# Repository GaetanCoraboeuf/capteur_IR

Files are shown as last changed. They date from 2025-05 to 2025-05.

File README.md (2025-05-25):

# capteur_IR

Le but de ce projet est de concevoir un capteur de détection de mouvement par infrarouges. Cette solution est modulable et scalable en plus de son coût de fabrication faible.

## Table des Matières

- [Description](#description)
- [Hardware](#hardware)
- [Software](#software)
- [Évolutions](#évolutions)
- [Contributeurs](#contributeurs)

## Description

Il est composé de deux grande parties:
 - Electronique (ESP32 + capteur IR LHI968)
 - Software (code C++ + dashboard avec base de données)

Ce projet a été fait par des étudiants.

## Hardware

La carte électronique est conçu pour être un sheld pour une Esp32 devkit V1.
On a utilisé KiCad pour la concevoir et générer le modèle 3D.
Et on l'a réalisé en prototypage rapide sur CNC.

Voici le schéma électronique :
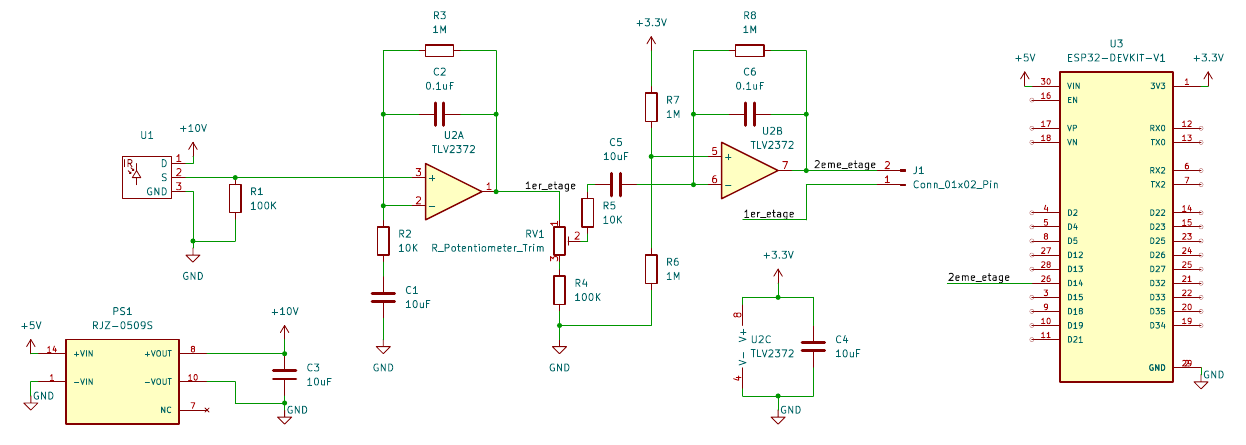
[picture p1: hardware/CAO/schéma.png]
Schéma élec


Et voici la réalisation final :
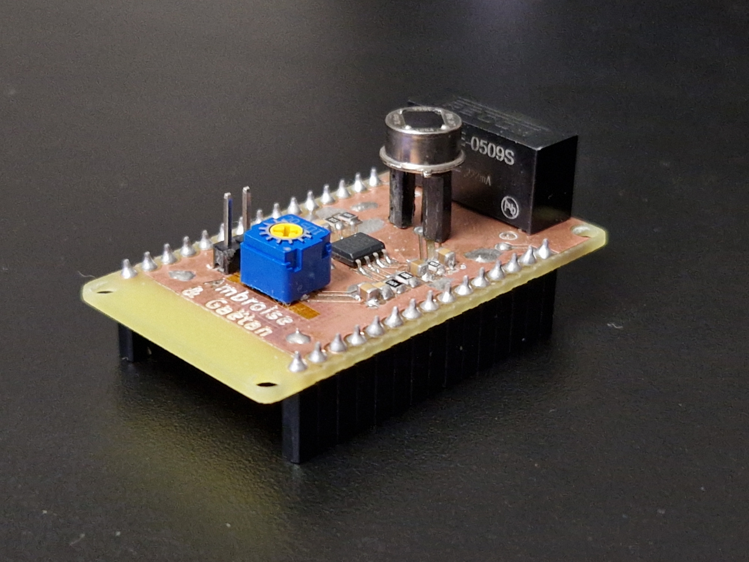
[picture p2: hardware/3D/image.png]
rendu carte finie


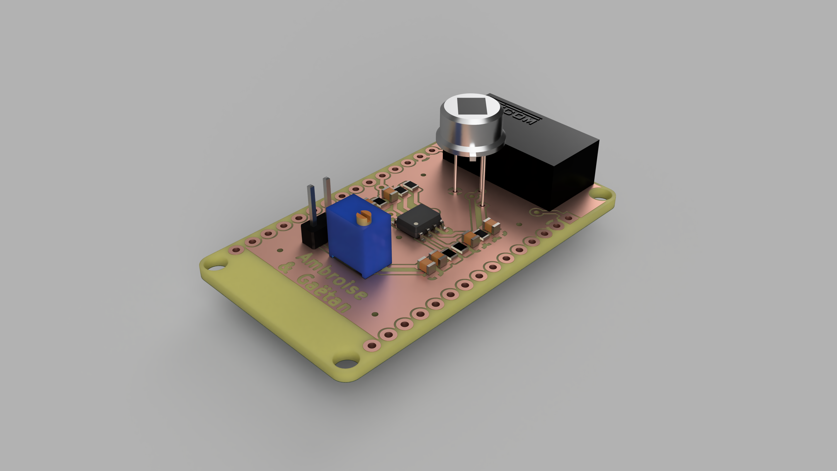
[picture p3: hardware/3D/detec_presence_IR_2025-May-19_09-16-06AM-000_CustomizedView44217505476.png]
rendu 3d de la carte


## Software

Ce code permet de se connecter à une base de données influxDB via une requête POST.
De notre côté on a choisi d'héberger cette base de données sur une Raspberry Pi et de l'exploiter avec Grafana.

Ce code envoie simplement la tesion du capteur toutes les 100ms à la base de données et tente une reconection au Wi-Fi chaque fois qui pert le signal.

## Boitier

Nous avons aussi conçu un boitier pour le capteur. Il est imprimé en 3D et permet d'intégrer tous les composants de manière esthétique et fonctionnelle. (merci à BHP pour la conception du boitier)

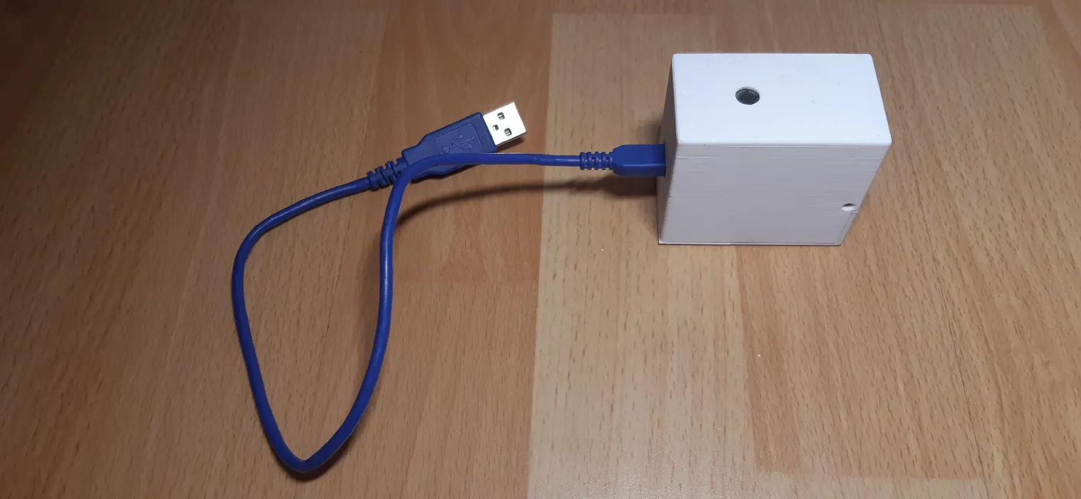
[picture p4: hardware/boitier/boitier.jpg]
boitier

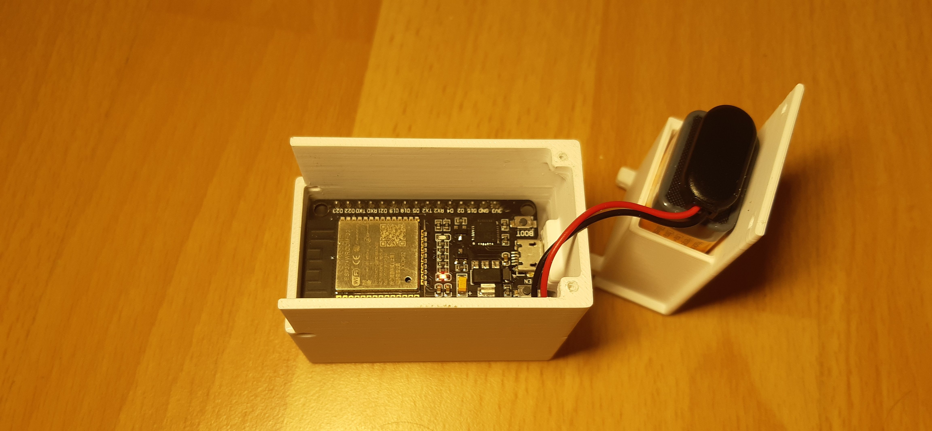
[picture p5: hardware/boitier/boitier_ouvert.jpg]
boitier ouvert


## Évolutions

- [x] Remplacement du convertisseur boost par une pile 9V (ce convertisseur n'est pas recomandé)
- [ ] Lecture de la tension de batterie avec un pont diviseur
- [ ] Scan des periphériques Bluethooth à proximité (distinction autorisé/non-autorisé)
- [ ] Detection sonore, bruit ambiant
- [ ] Camera avec intégration IA (OpenCV)
- [ ] Utiliser l'horloge temps réel de l'ESP32 pour horodater les valeurs grace à un serveur de temps (plus précis)
- [ ] Mettre en place un buffer en cas de coupure de connection pour ne pas perdre de valeurs

## Contributeurs

Ambroise Nedey-Crettaz <br />
Gaëtan Corabœuf

Sur la proposition de : <br />
M.Dumas

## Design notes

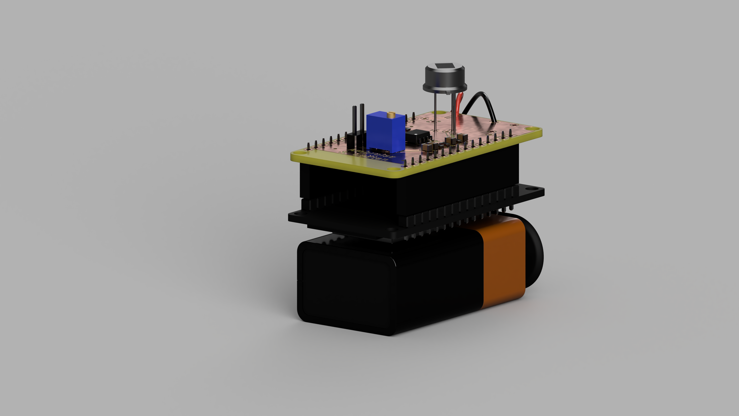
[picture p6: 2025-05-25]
hardware/3D/d7317d31-32a5-4699-8c03-88a2d2deff08.PNG

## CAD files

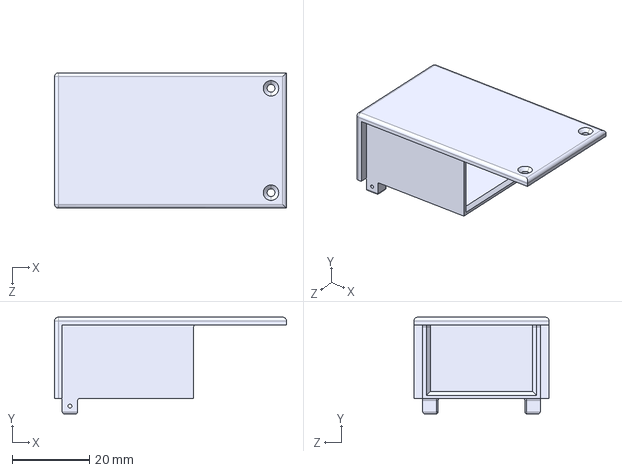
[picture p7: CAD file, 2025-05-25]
hardware/boitier/couvercle.STEP
60.0 x 25.0 x 35.0 mm

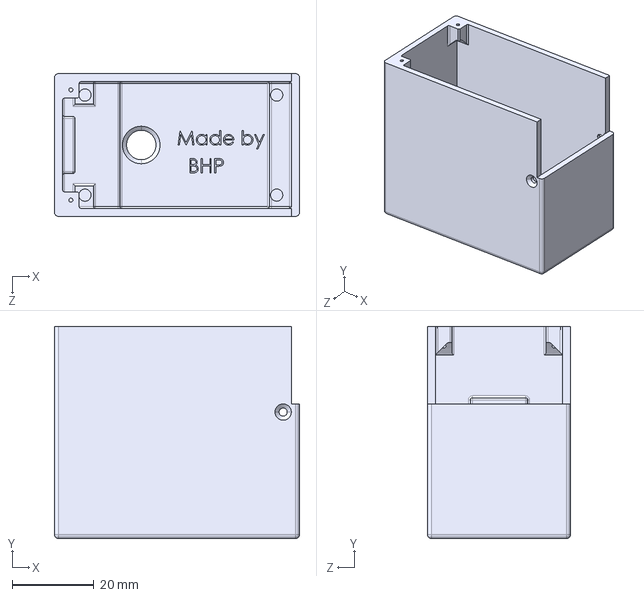
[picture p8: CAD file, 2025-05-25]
hardware/boitier/boite.STEP
60.0 x 52.0 x 35.0 mm

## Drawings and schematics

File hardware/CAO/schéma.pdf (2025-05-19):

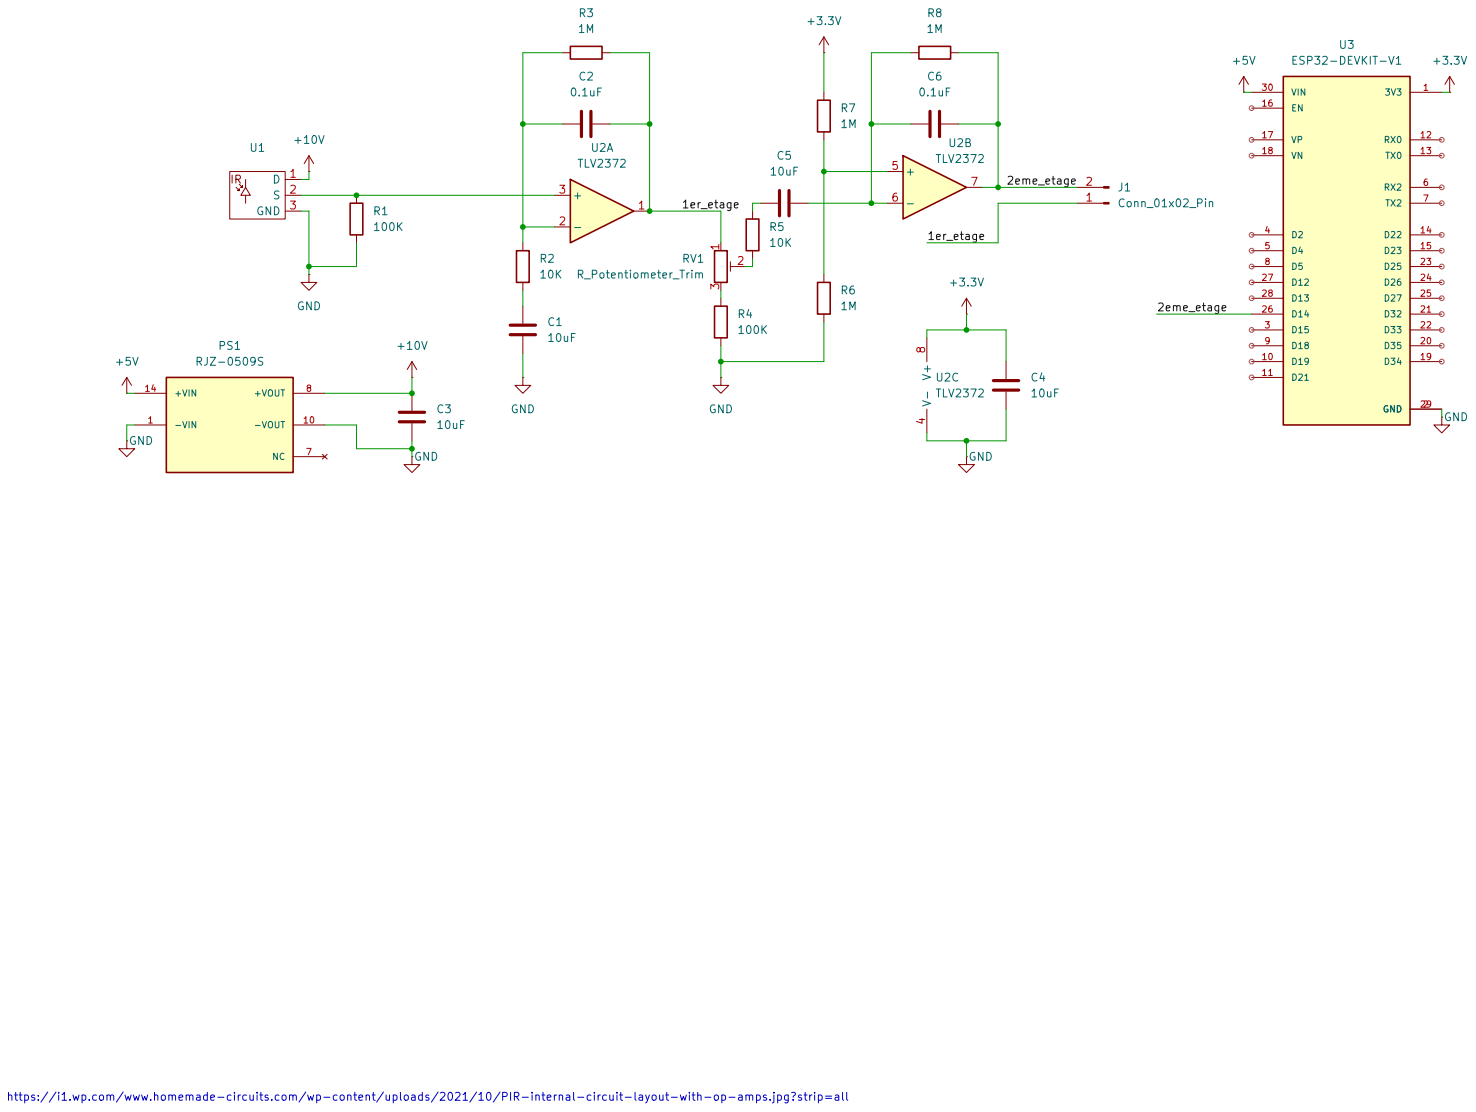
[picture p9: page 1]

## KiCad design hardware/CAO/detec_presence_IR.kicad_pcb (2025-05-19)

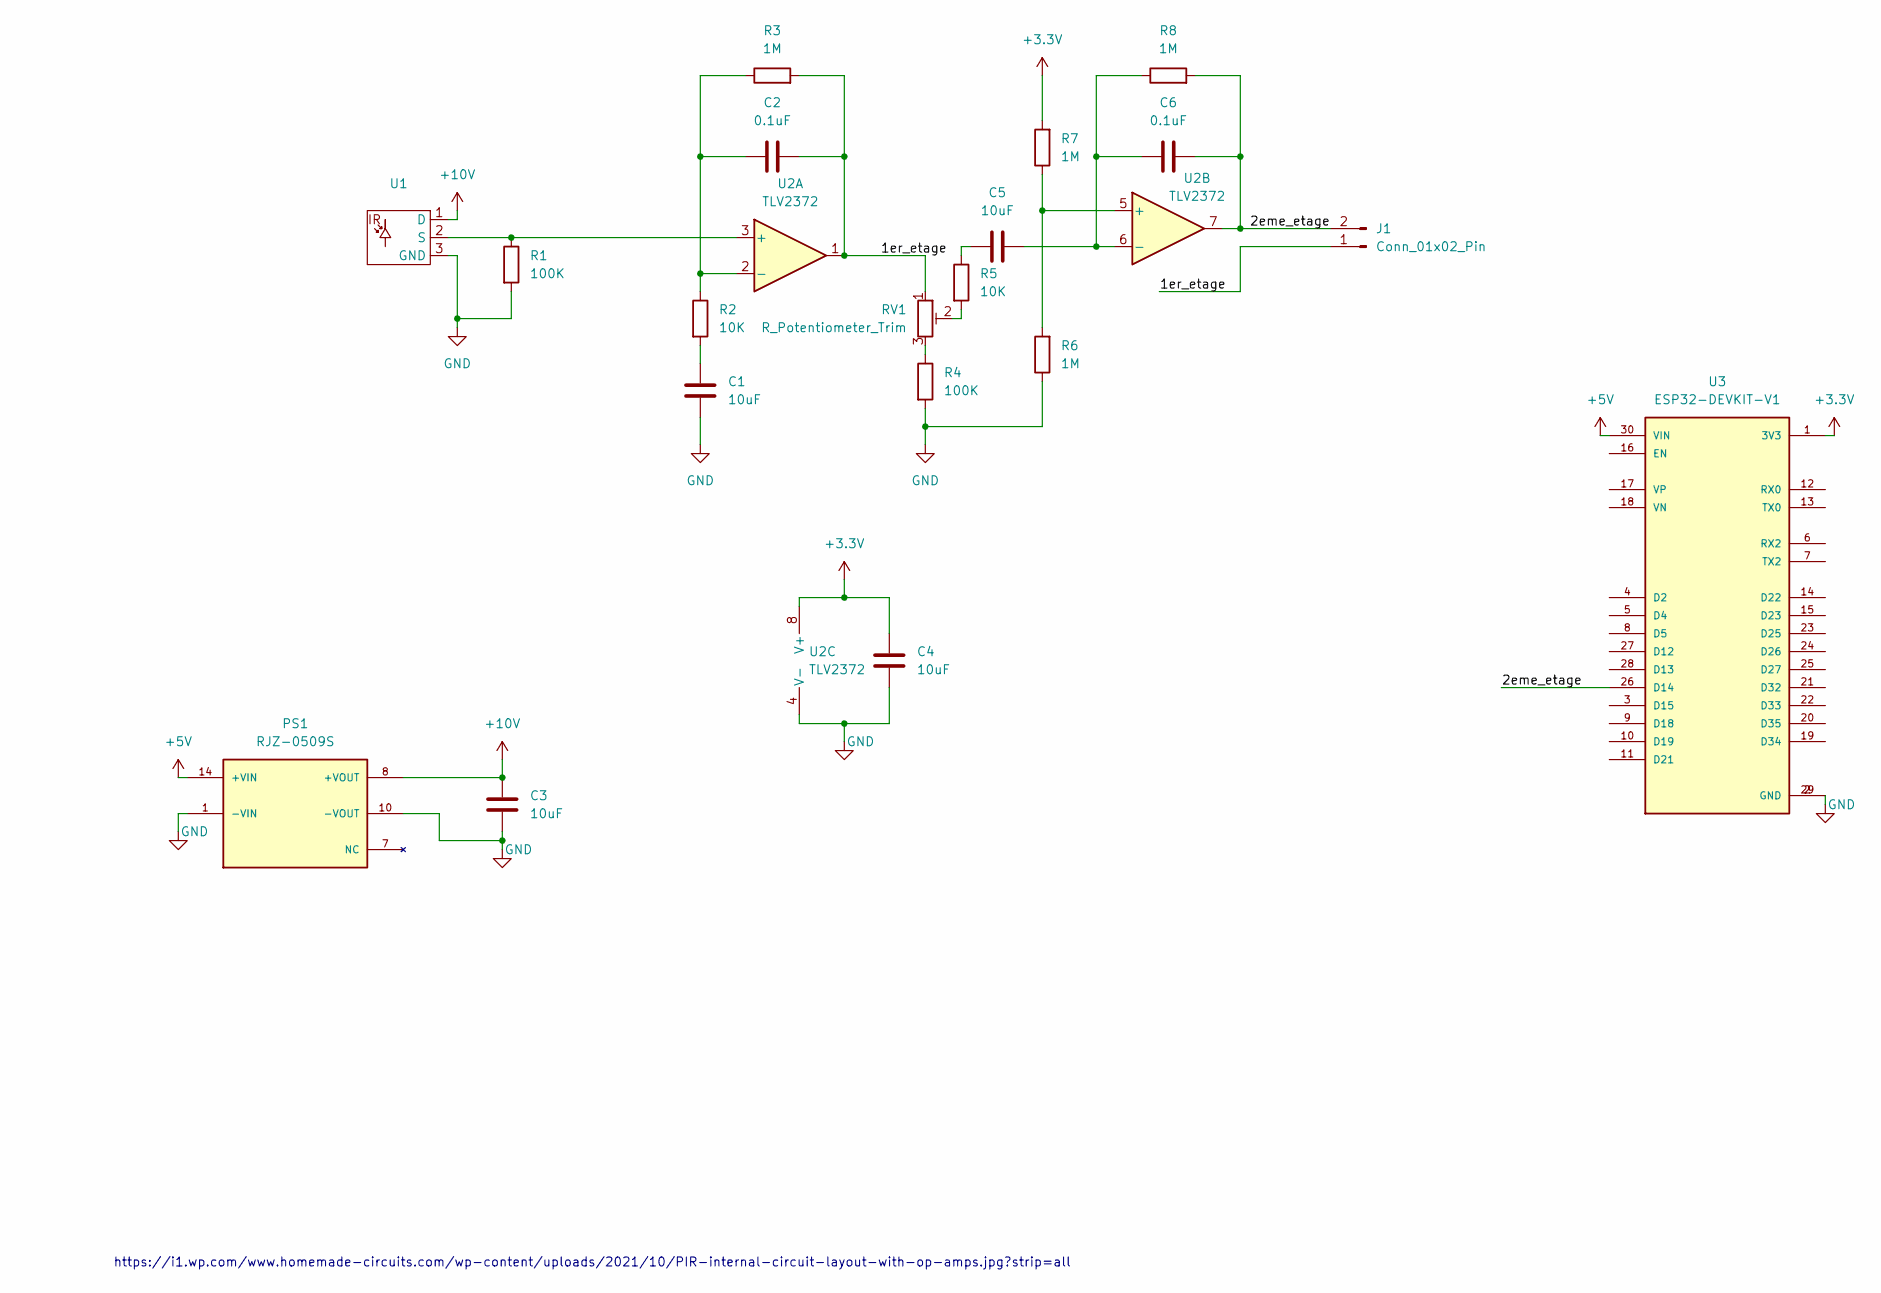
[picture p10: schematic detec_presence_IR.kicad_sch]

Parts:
C1, C3, C4, C5: 10uF; C_0805_2012Metric_Pad1.18x1.45mm_HandSolder
C2, C6: 0.1uF; C_0805_2012Metric_Pad1.18x1.45mm_HandSolder
J1: Conn_01x02_Pin; PinHeader_1x02_P2.54mm_Vertical
PS1: RJZ-0509S; RJZ-0509S_CONV_RJZ-0509S; PARTREV 1
R1, R4: 100K; R_0805_2012Metric_Pad1.20x1.40mm_HandSolder
R2, R5: 10K; R_0805_2012Metric_Pad1.20x1.40mm_HandSolder
R3, R6, R7, R8: 1M; R_0805_2012Metric_Pad1.20x1.40mm_HandSolder
RV1: R_Potentiometer_Trim; Potentiometer_Vishay_T93YA_Vertical
U1: TO254P940H1930-3
U2: TLV2372; SOIC-8_3.9x4.9mm_P1.27mm
U3: ESP32-DEVKIT-V1; ESP32-DEVKIT-V1_MODULE_ESP32_DEVKIT_V1; PARTREV N/A

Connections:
+3.3V: C4.1, R7.2, U2.8 (V+), U3.1 (3V3)
+5V: PS1.14 (+VIN), U3.30 (VIN)
+10V: C3.1, PS1.8 (+VOUT), U1.1 (D)
/1er_etage: C2.2, J1.1, R3.2, RV1.1, U2.1
/2eme_etage: C6.2, J1.2, R8.2, U2.7, U3.26 (D14)
GND: C1.2, C3.2, C4.2, PS1.1 (-VIN), PS1.10 (-VOUT), R1.2, R4.2, R6.1, U1.3 (GND), U2.4 (V-), U3.2 (GND), U3.29 (GND)
unnamed: C1.1, R2.2
unnamed: C5.1, R5.1
unnamed: R4.1, RV1.3
unnamed: R5.2, RV1.2
unnamed: R1.1, U1.2 (S), U2.3 (+)
unnamed: C2.1, R2.1, R3.1, U2.2 (-)
unnamed: R6.2, R7.1, U2.5 (+)
unnamed: C5.2, C6.1, R8.1, U2.6 (-)

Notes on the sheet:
https://i1.wp.com/www.homemade-circuits.com/wp-content/uploads/2021/10/PIR-internal-circuit-layout-with-op-amps.jpg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

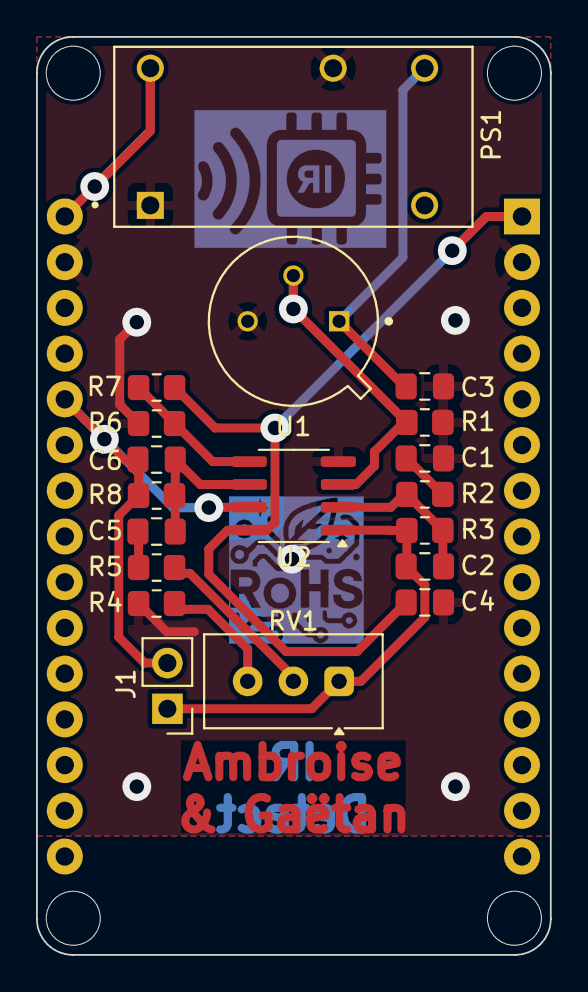
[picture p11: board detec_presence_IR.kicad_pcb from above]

Board: 2 copper layers, 28.6 x 51.0 mm, 20 parts (1 on the bottom side), 14 nets.

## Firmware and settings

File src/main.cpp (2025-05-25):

#include <Arduino.h>

#include <WiFi.h>
#include <HTTPClient.h>

#include <wifi_credentials.h> //fichier contenant les identifiants Wi-Fi



// Adresse et DB Influx
const char* influxHost = "http://192.168.1.137:8086/"; // Assure-toi que l'adresse IP correspond à ton serveur InfluxDB
const char* influxDb   = "mesure_iot"; // Nom de la base de données InfluxDB

// Broche analogique du capteur PIR
const int pirPin = 14;

void setup() {
  Serial.begin(115200);
  WiFi.begin(ssid, password);
  Serial.print("Connexion WiFi…");
  while (WiFi.status() != WL_CONNECTED) {
    delay(500);
    Serial.print('.');
  }
  Serial.println(" connecté !");
  // Initialise la broche en entrée si besoin
  pinMode(pirPin, INPUT);
}

void loop() {
  if (WiFi.status() == WL_CONNECTED) {
    // Lecture de la valeur brute (0–4095) et conversion en tension (0–3.3V)
    int raw = analogRead(pirPin);
    float tension = raw * (3.3f / 4095.0f);

    // Prépare la ligne InfluxDB (Line Protocol)
    // Ici : measurement = "presence", tag = "capteur=pir", field = "voltage"
    String lp = "presence,capteur=pir voltage=" + String(tension, 3);
    // Si tu veux un timestamp précis en secondes, ajoute :
    // lp += " " + String(time(NULL));

    // Envoi HTTP POST
    HTTPClient http;
    String url = String(influxHost) + "write?db=" + influxDb + "&precision=s";
    http.begin(url);
    http.addHeader("Content-Type", "text/plain");
    int code = http.POST(lp);

    if (code == 204 || code == 200) {
      Serial.printf("Données envoyées : %s → code %d\n", lp.c_str(), code);
    } else {
      Serial.printf("Erreur envoi (%d) : %s\n", code, http.getString().c_str());
    }
    http.end();
  } else {
    Serial.println("WiFi déconnecté, tentative de reconnexion…");
    WiFi.reconnect();
  }

  // Attente 100 ms
  delay(100);
}

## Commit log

2025-05-19 ajout hard
    [detec_presence_IR.kicad_pcb, detec_presence_IR.kicad_sch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]
2025-05-19 fin de journée
2025-05-25 mage readme + boitier
    [boite.STEP, couvercle.STEP]
2025-05-25 case afichage correct
